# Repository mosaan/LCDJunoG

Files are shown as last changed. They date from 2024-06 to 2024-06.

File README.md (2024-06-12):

Roland Juno G LCD Emulator
==========================

LCD replacement project for Roland Juno G.
The original source is [dpeddi's work](https://github.com/dpeddi/LCDJunoG) under BSD-3-Clause license.
```
 * Copyright (c) 2022 Eddi De Pieri
 * Most code borrowed by Pico-DMX by Jostein Løwer 
 * Modified for performance by bjaan
```

Slight modifications as follows
- (WIP) LCD now uses 8-bit parallel mode for better refresh rate.
- Pin definitions in `platformio.ini` now work correctly. See `platformio.ini` for pinout notes.
- Fix few minor bugs.
- Refactor codes for better readability.
- Remove `MODE_BRIGHTNESS` and change functionality of `MODE_BGCOLOR`. (see below)

About `MODE_BGCOLOR`
====================

In `MODE_BGCOLOR`, you can control LCD background color with `LCD CONTRAST` knob on Juno G.

- In the first 3/4 of the knob, a color is selected from the hue ring according to the knob position.
- In the remaining 1/4 of the knob, the background color is fixed at white.

Without `MODE_BGCOLOR`, background color fixed to white.

PlatformIO Build Environments
=============================

There are 2 environments defined:
- `env:pico`: LCD runs in SPI mode.
- `env:pico-parallel`: LCD runs in 8bit parallel mode.

Althogh predefined pin assignments are carefully selected to make PCB creation easier,
you can choose other pins to match your needs.

BOM:
====

- Raspberry Pi Pico
- Display ILI9488 4.0” (purchased from [AliExpress](https://ja.aliexpress.com/item/1005003033844928.html))
- 1.0mm pitch 18-pin flexible flat cable. Length: 210mm (shorter might work), contacts on same side.
- FFC/FPC connector
  - 1.0mm pitch 18-pin, bottom connection; for Juno G connection.
  - (Needed in parallel mode only) 0.5mm pitch 40-pin, top connection; for LCD connection.
- 5 to 10 ohm reistor; for backlight LED on LCD.
- (Optional) 0.1uF ceramic capacitor; for "LCD CONTRAST" knob stability.

Predefined Pin Assignments (Parallel mode):
===========================================

| JunoG Pin | JunoG Function | RpiPico Pin |
| --- | --- | --- |
| 18 | +5V | VSYS |
| 17 | GND | GND |
| 16 | +3V | (Not used)  |
| 15 | RST | GP21 |
| 14 | CS2 (*1) | GP20 |
| 13 | CS1 (*1) | GP19 |
| 12 | RS | GP18 |
| 11 | WE | GP17 |
| 10 | D0 | GP8 |
| 9 | D1 | GP9 |
| 8 | D2 | GP10 |
| 7 | D3 | GP11 |
| 6 | D4 | GP12 |
| 5 | D5 | GP13 |
| 4 | D6 | GP14 |
| 3 | D7 | GP15 |
| 2 | BRGT | GP28 |
| 1 | BRGT Vref | +3V |

*1: Check if the pin configuration might be reversed

| LCD Pin# | LCD Function  | RpiPico Pin |
| --- | --- | --- |
| 40 | IM2 | GND |
| 39 | IM1 | 3.3V |
| 38 | IM0 | 3.3V |
| 37 | GND | GND |
| 36 | LED-K | GND |
| 35 | LED-K | GND |
| 34 | LED-K | GND |
| 33 | LED-A | (3.3V via resistor) |
| 32 | DB15 | (not used) |
| 31 | DB14 | (not used) |
| 30 | DB13 | (not used) |
| 29 | DB12 | (not used) |
| 28 | DB11 | (not used) |
| 27 | DB10 | (not used) |
| 26 | DB9 | (not used) |
| 25 | DB8 | (not used) |
| 24 | DB7 | GP7 |
| 23 | DB6 | GP6 |
| 22 | DB5 | GP5 |
| 21 | DB4 | GP4 |
| 20 | DB3 | GP3 |
| 19 | DB2 | GP2 |
| 18 | DB1 | GP1 |
| 17 | DB0 | GP0 |
| 16 | GND | GND |
| 15 | RESET | GP22 |
| 14 | SPI SDO | (not used) |
| 13 | SPI SDI/SDA | (not used) |
| 12 | RDX | 3.3V |
| 11 | WRX/SPI SCL | GP26 |
| 10 | DCX/RS(SPI-4) | GP27 |
| 9 | CSX/SPI CS | GND |
| 8 | FMARK(TE) | (not used) |
| 7 | VDDA | 3.3V |
| 6 | VDDI | 3.3V |
| 5 | GND | GND |
| 4 | YD | (not used) |
| 3 | XR | (not used) |
| 2 | YU | (not used) |
| 1 | XL | (not used) |

Predefined Pin Assignments (SPI mode):
======================================

| JunoG Pin | JunoG Function | RpiPico Pin |
| --- | --- | --- |
| 18 | +5V | VSYS |
| 17 | GND | GND |
| 16 | +3V | (Not used)  |
| 15 | RST | GP14 |
| 14 | CS1 | GP12 |
| 13 | CS2 | GP13 |
| 12 | RS | GP11 |
| 11 | WE | GP10 |
| 10 | D0 | GP2 |
| 9 | D1 | GP3 |
| 8 | D2 | GP4 |
| 7 | D3 | GP5 |
| 6 | D4 | GP6 |
| 5 | D5 | GP7 |
| 4 | D6 | GP8 |
| 3 | D7 | GP9 |
| 2 | BRGT | GP26 |
| 1 | BRGT Vref | +3V |

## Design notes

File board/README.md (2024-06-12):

# Reference board design

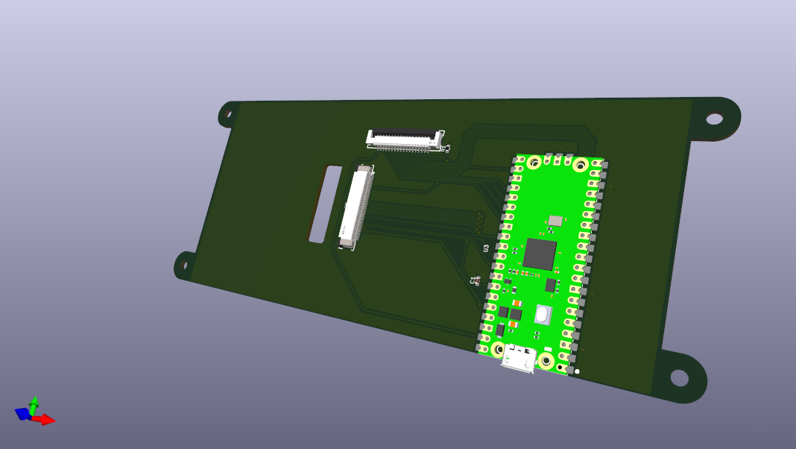
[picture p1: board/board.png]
reference board image


This directory contains [atopile](https://atopile.io/) & [KiCad](https://www.kicad.org/) project files for the reference board design.

If you just need PCB gerber files, see `elec/layout/default/production/board.zip`.

## Folder & File structure

- `ato.yaml`: atopile project setting file. see [atopile documentation](https://atopile.io/config/).
- `elec/`: main project files related with atopile and KiCad
  - `footprints/`: KiCad footprints & 3D shape datas.
  - `layout/`: KiCad project files.
  - `src/`: atopile module files.

## To modify & build your own gerber files

1. Modify `elec/src/board.ato` as you like.
2. [Install atopile](https://atopile.io/getting-started/) and run `ato install & ato build` in this folder, then you got netlist file at `build/default.net`.
3. Open `elec/layout/board.kicad_pro` in KiCad and open PCB file (or just open `elec/layout/board.kicad_pcb`).
4. From `File` menu, select `Import -> Netlist...`, then select the generated netlist file.
5. Now netlist updated as you write in `elec/src/board.ato`. Change board layout as you like!

Subsequent steps is the same as the usual board design in KiCad. Refer to  KiCad documentation.

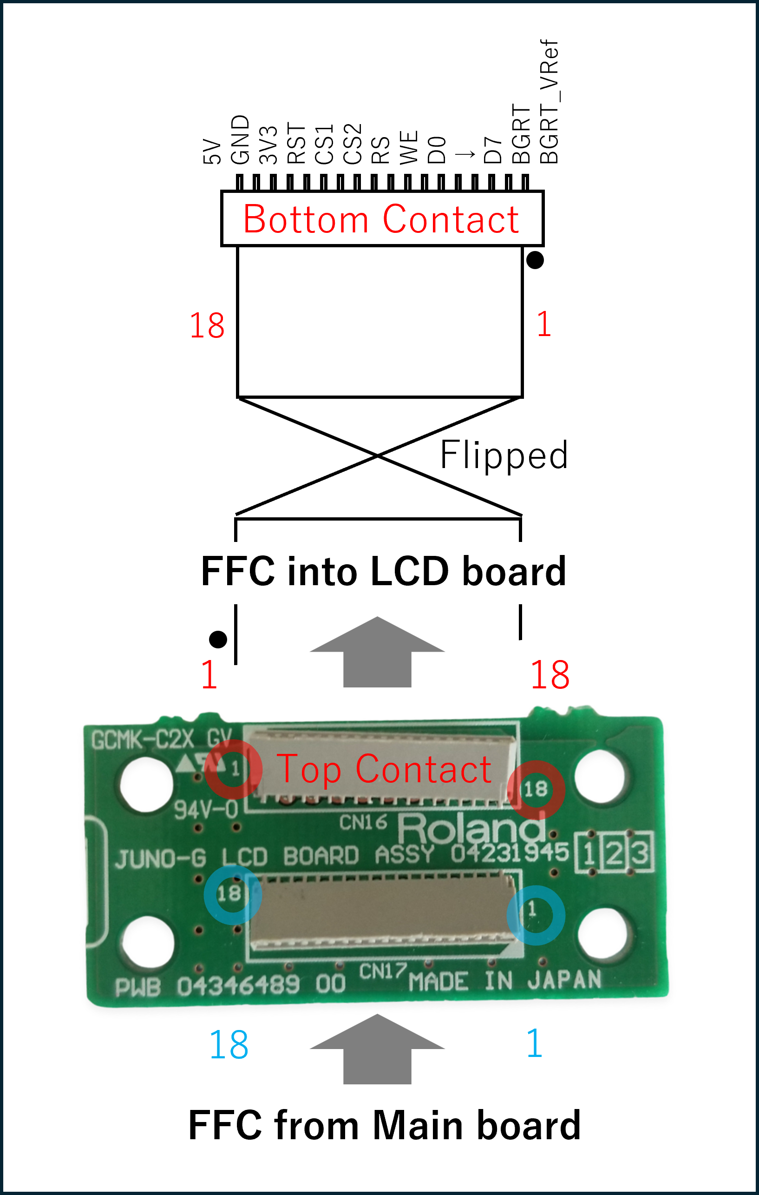
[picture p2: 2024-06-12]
docs/JunoG_to_LCDModule_connection_reference.png

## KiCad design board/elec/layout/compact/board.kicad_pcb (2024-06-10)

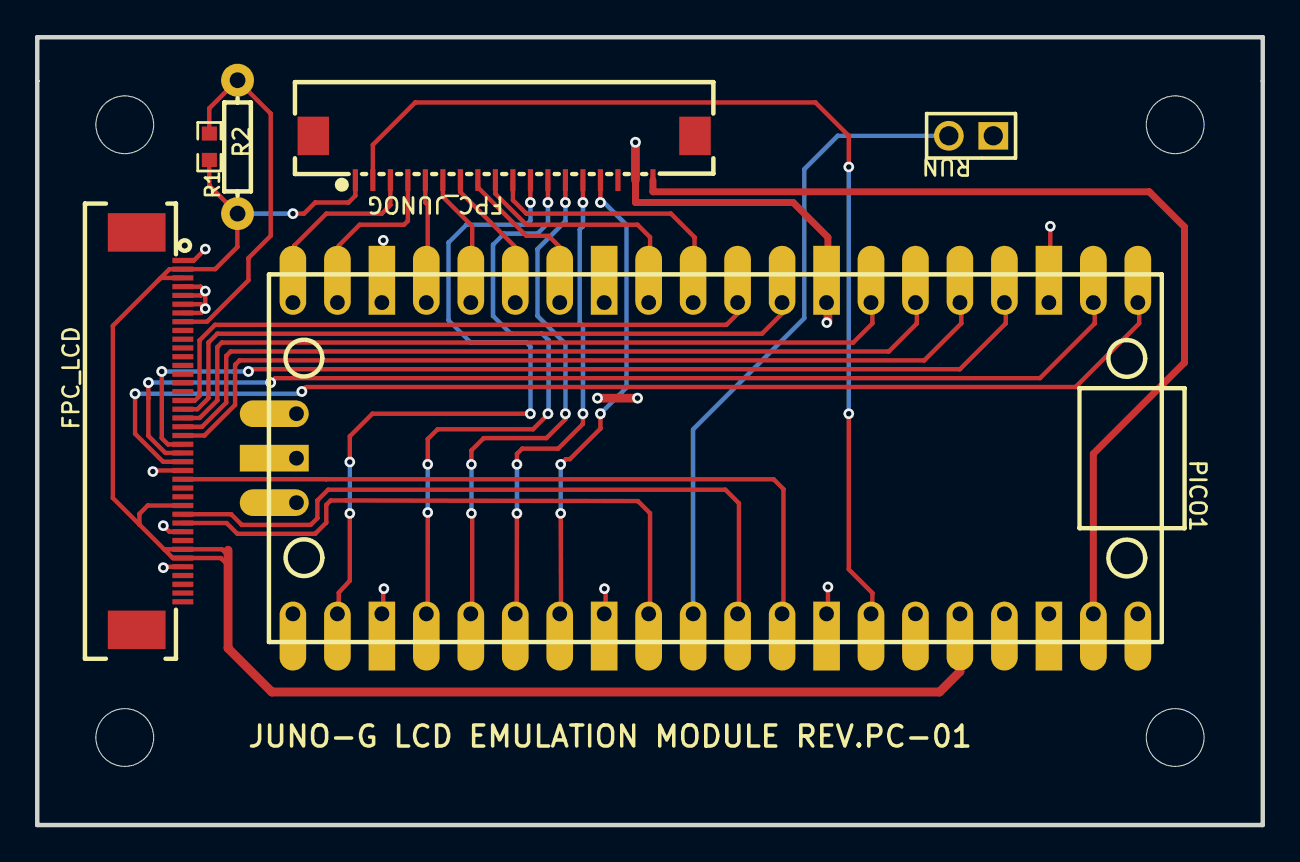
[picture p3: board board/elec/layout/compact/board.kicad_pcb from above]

Board: 2 copper layers, 70.0 x 45.0 mm, 10 parts (0 on the bottom side), 30 nets.

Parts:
FPC_JUNOG: 1.0K-DX-18PWB; FPC-SMD_18P-P1.00_HDGC_1.0K-DX-18PWB
FPC_LCD: AFC07-S40ECA-00; FPC-SMD_P0.50-40P_LCS-SJ-H2.0
Hole_gge3520: Hole_gge3520
Hole_gge3523: Hole_gge3523
Hole_gge3526: Hole_gge3526
Hole_gge3529: Hole_gge3529
PICO1: RASPBERRY-PI-PICO_TH/SMT (No Debug Pins); RASPBERRY-PI-PICO
R1: 5R1; R0603
R2: 5R1; R_AXIAL-0.3
RUN: HDR-M-2.54_1x2; HDR-M-2.54_1X2

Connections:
3.3V: FPC_JUNOG.1, FPC_LCD.2, FPC_LCD.3, FPC_LCD.29, FPC_LCD.34, FPC_LCD.35, PICO1.36, R1.1, R2.1
+5V: FPC_JUNOG.18, PICO1.39
BGRT: FPC_JUNOG.2, PICO1.34
CS1: FPC_JUNOG.14, PICO1.26
CS2: FPC_JUNOG.13, PICO1.25
D0: FPC_JUNOG.10, PICO1.11
D1: FPC_JUNOG.9, PICO1.12
D2: FPC_JUNOG.8, PICO1.14
D3: FPC_JUNOG.7, PICO1.15
D4: FPC_JUNOG.6, PICO1.16
D5: FPC_JUNOG.5, PICO1.17
D6: FPC_JUNOG.4, PICO1.19
D7: FPC_JUNOG.3, PICO1.20
FPC_LCD_8: FPC_LCD.8, R1.2, R2.2
GND: FPC_JUNOG.17, FPC_LCD.1, FPC_LCD.4, FPC_LCD.5, FPC_LCD.6, FPC_LCD.7, FPC_LCD.25, FPC_LCD.32, FPC_LCD.36, PICO1.3, PICO1.8, PICO1.13, PICO1.18, PICO1.23, PICO1.28, PICO1.33, PICO1.38, RUN.1
LCD_DB0: FPC_LCD.24, PICO1.1
LCD_DB1: FPC_LCD.23, PICO1.2
LCD_DB2: FPC_LCD.22, PICO1.4
LCD_DB3: FPC_LCD.21, PICO1.5
LCD_DB4: FPC_LCD.20, PICO1.6
LCD_DB5: FPC_LCD.19, PICO1.7
LCD_DB6: FPC_LCD.18, PICO1.9
LCD_DB7: FPC_LCD.17, PICO1.10
LCD_DC: FPC_LCD.31, PICO1.29
LCD_RST: FPC_LCD.26, PICO1.32
LCD_WR: FPC_LCD.30, PICO1.31
PICO1_30: PICO1.30, RUN.2
RS: FPC_JUNOG.12, PICO1.24
RST: FPC_JUNOG.15, PICO1.27
WE: FPC_JUNOG.11, PICO1.22

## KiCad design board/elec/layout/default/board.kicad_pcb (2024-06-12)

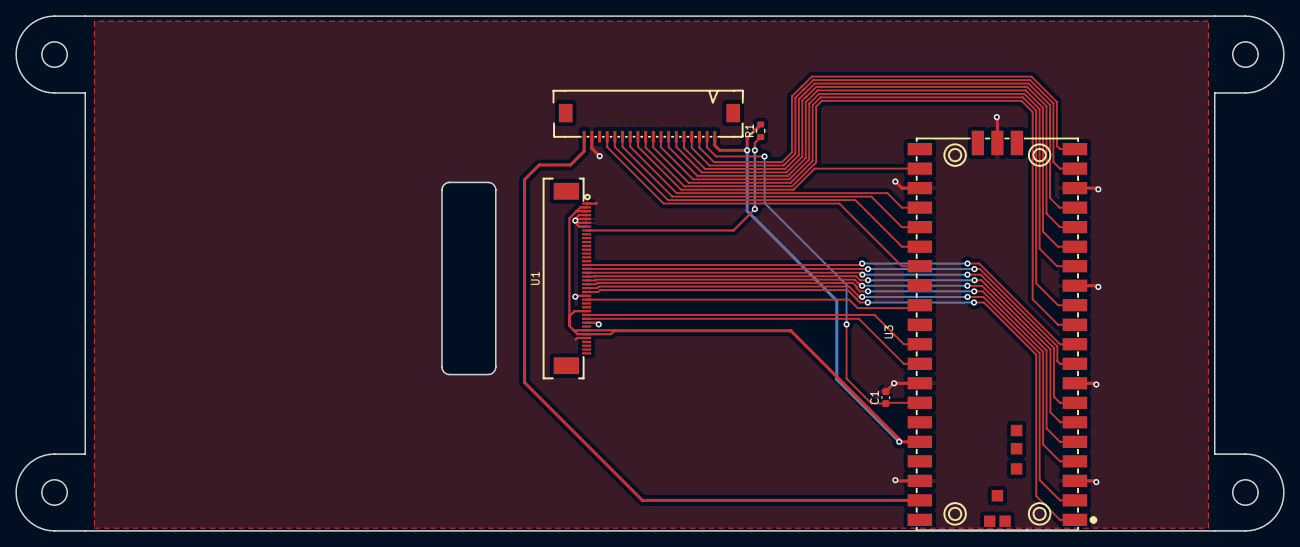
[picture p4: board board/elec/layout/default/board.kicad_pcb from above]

Board: 2 copper layers, 165.0 x 67.0 mm, 5 parts (0 on the bottom side), 29 nets.

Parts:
C1: 50V 100nF X7R ±10% 0603 Multilayer Ceramic Capaci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; C0603
R1: 100mW Thick Film Resistors 75V ±1% ±400ppm/℃ 10Ω 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; R0603
U1: FPC-SMD_P0.50-40P_LCS-SJ-H2.0
U2: FPC-SMD_AFA01-S18FCC-00
U3: COMM-SMD_L51.0-W21.0-P2.54_SC0916

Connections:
brgt: C1.1, U2.2, U3.34
cs1: U2.13, U3.25
cs2: U2.14, U3.26
d0: U2.10, U3.11
d1: U2.9, U3.12
d2: U2.8, U3.14
d3: U2.7, U3.15
d4: U2.6, U3.16
d5: U2.5, U3.17
d6: U2.4, U3.19
d7: U2.3, U3.20
db0: U1.24, U3.1
db1: U1.23, U3.2
db2: U1.22, U3.4
db3: U1.21, U3.5
db4: U1.20, U3.6
db5: U1.19, U3.7
db6: U1.18, U3.9
db7: U1.17, U3.10
dcx_rs_spi: U1.31, U3.32
gnd: C1.2, U1.1, U1.4, U1.5, U1.6, U1.7, U1.25, U1.32, U1.36, U2.17, U3.3, U3.8, U3.13, U3.18, U3.23, U3.28, U3.33, U3.38, U3.42
led_a: R1.1, U1.8
reset: U1.26, U3.29
rs: U2.12, U3.24
rst: U2.15, U3.27
vdd3: R1.2, U1.2, U1.3, U1.29, U1.34, U1.35, U2.1, U3.36
vdd5: U2.18, U3.39
we: U2.11, U3.22
wrx_spi_scl: U1.30, U3.31

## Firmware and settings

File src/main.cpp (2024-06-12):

/*
 * Copyright (c) 2022 Eddi De Pieri
 * Most code borrowed by Pico-DMX by Jostein Løwer 
 * Modified for performance by bjaan
 *
 * SPDX-License-Identifier: BSD-3-Clause
 * 
 * Description: 
 * Roland Juno G LCD Emulator
 */

// Define in setup to disable all #warnings in library (can be put in User_Setup_Select.h)
#define DISABLE_ALL_LIBRARY_WARNINGS
#ifdef DEBUG_SERIAL
#define DEBUG_PRINT(content) DEBUG_PRINT(content)
#else
#define DEBUG_PRINT(content) // do nothing.
#endif

#ifdef TFT_PARALLEL_8_BIT
// parallel mode does not need to call startWrite() and endWrite()
#define TFT_START_WRITE
#define TFT_END_WRITE
#else // SPI mode
#define TFT_START_WRITE tft.startWrite()
#define TFT_END_WRITE tft.endWrite()
#endif

#include <Arduino.h>

#include <SPI.h>
#include <TFT_eSPI.h> // Hardware-specific library
#ifdef DRAW_SPLASH
#include <LCDJunoG_splash.h>
#endif
#include <LCDJunoG_extra.h>

TFT_eSPI tft = TFT_eSPI();       // Invoke custom library

#include "LCDJunoG.h"
LCDJunoG lcdJunoG_cs1;
LCDJunoG lcdJunoG_cs2;

#include "constants.h"

uint tft_xoffset = 0;
uint tft_yoffset = 0;

/* 
  buffer_cs1[i]: raw data buffer sent from JUNO-G.

    bits:
    FEDCBA98 76543210 FEDCBA98 76543210
    ???????? ???????? ???????? vvvvvvvv
    s = R/S (INSTRUCTION/DATA REGISTER SELECTION) pin data (see JUNO_RS in platformio.ini and RS_PIN_RELATIVE_POSITION)
    v = value bits (8 bits: values 0 up to and including 255). y-axis values for 8 pixels packed into 1 byte.
*/
volatile uint32_t buffer_cs1[RAW_DATA_BUFFER_LENGTH];

/* 
  buffer_cs2[i]: raw data buffer sent from JUNO-G.

    bits:
    FEDCBA98 76543210 FEDCBA98 76543210
    ???????? ???????? ???????? vvvvvvvv
    s = R/S (INSTRUCTION/DATA REGISTER SELECTION) pin data (see JUNO_RS in platformio.ini and RS_PIN_RELATIVE_POSITION)
    v = value bits (8 bits: values 0 up to and including 255). y-axis values for 8 pixels packed into 1 byte.
*/
volatile uint32_t buffer_cs2[RAW_DATA_BUFFER_LENGTH];

// === buffer_cs1 and buffer_cs2 bit manipulation ===
// Extracts the value bits from the buffer_cs1 and buffer_cs2
#define VALUE_BITS(value) (value & 0xff)
// Extracts the RS bit from the buffer_cs1 and buffer_cs2
#define RS_BIT(value) ((value >> RS_PIN_RELATIVE_POSITION) & 1)

volatile uint8_t back_buffer[ORIGINAL_LCD_WIDTH][Y_PACKED_BYTES_LENGTH]; /* max X address register for CS1 and CS2 times max Y register */
volatile uint16_t pixel_x[ORIGINAL_LCD_WIDTH]; /* X location (pre-calculated) of actual pixel on new screen */
volatile uint16_t pixel_y[ORIGINAL_LCD_HEIGHT]; /* Y location (pre-calculated) of actual pixel on new screen */

#define ADC_RESOLUTION 6
uint32_t tft_fgcolor = TFT_BLACK;
uint32_t tft_bgcolor = TFT_WHITE;
uint32_t tft_bgcolor_prev = TFT_BLACK;

/*
  Draws a packed_pixels byte on the TFT screen at x,y_index

  arguments:
  - packed_pixels: 8 pixels packed into 1 byte. MSB is the top pixel, LSB is the bottom pixel.
  - y_index: the y index of the pixel. packed_pixels is drawn at y_index*8 up to and including y_index*8+7, thus 0 <= y_index < 12 (= Y_PACKED_BYTES_LENGTH).
  - x: the x address of the pixel
 */
void drawPixels(uint8_t packed_pixels, uint8_t x, uint8_t y_index) {
  int16_t real_x = pixel_x[x];
  int8_t y = y_index * 8;
  //for (int b = 0; b < 8; b++ ) {
  //  if (((packed_pixels >> b) & 0x1) == 1) tft.drawPixel(real_x, pixel_y[y+b], TFT_BLACK); else tft.drawPixel(real_x, pixel_y[y+b], TFT_WHITE);
  //}
  //unrolled loop for performance:
#if (TFT_PARALLEL_8_BIT & !FORCE_INTERLACE) // 8-bit parallel mode. fill pixels with fillRect()
  if ((packed_pixels & 0x1) == 0x1)   tft.fillRect(real_x, pixel_y[y++], ZOOM_X, ZOOM_Y, TFT_BLACK); else tft.fillRect(real_x, pixel_y[y++], ZOOM_X, ZOOM_Y, tft_bgcolor);
  if ((packed_pixels & 0x2) == 0x2)   tft.fillRect(real_x, pixel_y[y++], ZOOM_X, ZOOM_Y, TFT_BLACK); else tft.fillRect(real_x, pixel_y[y++], ZOOM_X, ZOOM_Y, tft_bgcolor);
  if ((packed_pixels & 0x4) == 0x4)   tft.fillRect(real_x, pixel_y[y++], ZOOM_X, ZOOM_Y, TFT_BLACK); else tft.fillRect(real_x, pixel_y[y++], ZOOM_X, ZOOM_Y, tft_bgcolor);
  if ((packed_pixels & 0x8) == 0x8)   tft.fillRect(real_x, pixel_y[y++], ZOOM_X, ZOOM_Y, TFT_BLACK); else tft.fillRect(real_x, pixel_y[y++], ZOOM_X, ZOOM_Y, tft_bgcolor);
  if ((packed_pixels & 0x10) == 0x10) tft.fillRect(real_x, pixel_y[y++], ZOOM_X, ZOOM_Y, TFT_BLACK); else tft.fillRect(real_x, pixel_y[y++], ZOOM_X, ZOOM_Y, tft_bgcolor);
  if ((packed_pixels & 0x20) == 0x20) tft.fillRect(real_x, pixel_y[y++], ZOOM_X, ZOOM_Y, TFT_BLACK); else tft.fillRect(real_x, pixel_y[y++], ZOOM_X, ZOOM_Y, tft_bgcolor);
  if ((packed_pixels & 0x40) == 0x40) tft.fillRect(real_x, pixel_y[y++], ZOOM_X, ZOOM_Y, TFT_BLACK); else tft.fillRect(real_x, pixel_y[y++], ZOOM_X, ZOOM_Y, tft_bgcolor);
  if ((packed_pixels & 0x80) == 0x80) tft.fillRect(real_x, pixel_y[y  ], ZOOM_X, ZOOM_Y, TFT_BLACK); else tft.fillRect(real_x, pixel_y[y  ], ZOOM_X, ZOOM_Y, tft_bgcolor);
#else // SPI mode. SPI is too slow to draw all LCD pixels. So we draw interlaced pixels.
  if ((packed_pixels & 0x1) == 0x1)   tft.drawPixel(real_x, pixel_y[y++], TFT_BLACK); else tft.drawPixel(real_x, pixel_y[y++], tft_bgcolor);
  if ((packed_pixels & 0x2) == 0x2)   tft.drawPixel(real_x, pixel_y[y++], TFT_BLACK); else tft.drawPixel(real_x, pixel_y[y++], tft_bgcolor);
  if ((packed_pixels & 0x4) == 0x4)   tft.drawPixel(real_x, pixel_y[y++], TFT_BLACK); else tft.drawPixel(real_x, pixel_y[y++], tft_bgcolor);
  if ((packed_pixels & 0x8) == 0x8)   tft.drawPixel(real_x, pixel_y[y++], TFT_BLACK); else tft.drawPixel(real_x, pixel_y[y++], tft_bgcolor);
  if ((packed_pixels & 0x10) == 0x10) tft.drawPixel(real_x, pixel_y[y++], TFT_BLACK); else tft.drawPixel(real_x, pixel_y[y++], tft_bgcolor);
  if ((packed_pixels & 0x20) == 0x20) tft.drawPixel(real_x, pixel_y[y++], TFT_BLACK); else tft.drawPixel(real_x, pixel_y[y++], tft_bgcolor);
  if ((packed_pixels & 0x40) == 0x40) tft.drawPixel(real_x, pixel_y[y++], TFT_BLACK); else tft.drawPixel(real_x, pixel_y[y++], tft_bgcolor);
  if ((packed_pixels & 0x80) == 0x80) tft.drawPixel(real_x, pixel_y[y  ], TFT_BLACK); else tft.drawPixel(real_x, pixel_y[y  ], tft_bgcolor);
#endif
}

void fillScreenWithBackgroundColor(uint32_t bgcolor) {
  TFT_START_WRITE;
#if (TFT_PARALLEL_8_BIT & !FORCE_INTERLACE) // 8-bit parallel mode. just fill screen with fillScreen().
  tft.fillScreen(bgcolor);
#else // SPI mode. SPI is too slow to draw all LCD pixels. So we draw interlaced pixels with bgcolor and all the rest filled with Black.
  tft.fillScreen(TFT_BLACK);
  for (uint x = 0; x < ORIGINAL_LCD_WIDTH; x++) {
    for (uint y = 0; y < Y_PACKED_BYTES_LENGTH; y++) {
        drawPixels(0, x, y);
    }
  }
#endif
  TFT_END_WRITE;
}

// convert hue to rgb565 value
// saturation and value are fixed to max value.
uint16_t inline rgb565FromHue(uint8_t hue) {
  uint8_t r = 0, g = 0, b = 0;
  if (hue < 85) {
    r = hue * 3;
    g = 255 - hue * 3;
  } else if (hue < 170) {
    hue -= 85;
    g = hue * 3;
    b = 255 - hue * 3;
  } else {
    hue -= 170;
    b = hue * 3;
    r = 255 - hue * 3;
  }
  return tft.color565(r, g, b);
}

void tft_change_bgcolor(uint32_t analog_read) {
  // we use upper 1/4 value of the ADC resolution as a threshold to switch between black and white mode.
  uint8_t mode_val = (analog_read >> (ADC_RESOLUTION - 2));
  // 2 MSBits are ignored
  uint8_t color_val = (analog_read & ((1 << (ADC_RESOLUTION - 2)) - 1));
  if(mode_val == 0b11) { // white mode
    tft_bgcolor = TFT_WHITE;
  } else {
    uint8_t hue = map(color_val, 0, (1 << (ADC_RESOLUTION - 2)) - 1, 0, 255);
    tft_bgcolor = rgb565FromHue(hue);
  }

  if (tft_bgcolor != tft_bgcolor_prev) {
    DEBUG_PRINT("force redraw");
    tft_bgcolor_prev = tft_bgcolor;
    fillScreenWithBackgroundColor(tft_bgcolor);
    for(uint8_t x = 0; x < ORIGINAL_LCD_WIDTH; x++) {
      for(uint8_t y = 0; y < Y_PACKED_BYTES_LENGTH; y++) {
        drawPixels(back_buffer[x][y], x, y);
      }
    }
  }
}

void setup()
{
  analogReadResolution(ADC_RESOLUTION);
  uint32_t analog_read = analogRead(JUNO_BRGT);
#ifdef DEBUG_SERIAL
  Serial.begin(115200);
  delay(2000);
  Serial.setTimeout(50);
#endif

  DEBUG_PRINT("juno g lcd emulator");
  tft.init();
  tft.setRotation(1);
#ifdef TFT_PARALLEL_8_BIT
  tft.initDMA(); // Enable DMA transfer for parallel mode
#endif
  tft_xoffset = (tft.width() - ORIGINAL_LCD_WIDTH * ZOOM_X) / 2 - ((tft.width() - ORIGINAL_LCD_WIDTH * ZOOM_X) / 2 % ZOOM_X);
  tft_yoffset = (tft.height() - ORIGINAL_LCD_HEIGHT * ZOOM_Y) / 2 - ((tft.height() - ORIGINAL_LCD_HEIGHT * ZOOM_Y) / 2 % ZOOM_Y);

#ifdef DRAW_SPLASH
  tft_change_bgcolor();
  drawBitmapZoom(0, 0, (const uint8_t *)junog, 240, 90, TFT_BLACK);
  delay(500);
#endif

  {  //precalculate new display pixel indices
    for (uint8_t x = 0; x < ORIGINAL_LCD_WIDTH; x++) {
      pixel_x[x] = tft_xoffset + x * ZOOM_X;
    }
    for (uint8_t y = 0; y < ORIGINAL_LCD_HEIGHT; y++) {
      pixel_y[y] = tft_yoffset + y * ZOOM_Y;
    }
  }
  { //initialize back buffer
    for (uint8_t x = 0; x < ORIGINAL_LCD_WIDTH; x++) {
      for (uint8_t y = 0; y < Y_PACKED_BYTES_LENGTH; y++) {
        back_buffer[x][y] = 0;
      }
    }
  }

#define DRAW_INFO
#ifdef DRAW_INFO
#ifdef MODE_BGCOLOR
  tft_change_bgcolor(analog_read);
#endif
  tft.setTextColor(TFT_BLACK);
  tft.setCursor(0, tft.height()/2 -10  , 2);
  tft.setTextSize(2);
  
  tft.setTextDatum(TC_DATUM);
  tft.drawString("JunoG LCD replacement V2.1.3", tft.width() /2, tft.height() / 2 - 20 );
  //tft.drawString("CPU_FREQ:" + String(rp2040.f_cpu()), tft.width() /2, tft.height() / 2 + 10 );
  delay(500);
  fillScreenWithBackgroundColor(tft_bgcolor);
#endif

#ifdef DRAW_PINOUT  
  drawPinout(1000);
#endif
   
  tft.setCursor(0, 0, 2);
  tft.setTextSize(1);
  
  // Setup our DMX Input to read on GPIO 0, from channel 1 to 3
  // TFT_eSPI uses all of instruction memory of pio0 or pio1,
  // so we use pio1 for both(CS1/CS2) chip monitoring to keep enough memory for TFT_eSPI.
  // (TFT_eSPI consumes 32 PIO instructions. see ".pio/libdeps/pico/TFT_eSPI/Processors/pio_SPI.pio.h")
  lcdJunoG_cs1.begin(JUNO_D0, /* pio0 */ pio1, 1);
  lcdJunoG_cs2.begin(JUNO_D0, pio1, 2);
  lcdJunoG_cs1.read_async(buffer_cs1);
  lcdJunoG_cs2.read_async(buffer_cs2);

  // Setup the onboard LED so that we can blink when we receives packets
  pinMode(LED_BUILTIN, OUTPUT);
  DEBUG_PRINT("Setup finished");
}

volatile uint8_t x_cs1 = 0; //X address counter for CS1: 7 bit: values 0 up and to including 127: actually max. 120
volatile uint8_t x_cs2 = CS2_X_OFFSET; //X address counter for CS2: 7 bit: values 0 up and to including 127: actually max. 120. Here it is set, and later reset to 120, to avoid having to add an offset of 120 all the time
volatile uint8_t y_cs1 = 0; //Y address register for CS1: 4 bit: values 0 up and to including 15: actually max. 12 as 12*8 = 96
volatile uint8_t y_cs2 = 0; //Y address register for CS2: 4 bit: values 0 up and to including 15: actually max. 12 as 12*8 = 96

bool led_on = false;
unsigned long latest_packet_timestamp_cs1 = 0;
unsigned long latest_packet_timestamp_cs2 = 0;

int period = 500;
unsigned long time_last_adc_read = 0;
unsigned long time_now = 0;

void loop()
{
// TODO: Move the other core to handle bgcolor changes
#if MODE_BGCOLOR | DEBUG_READ
  time_now = millis();

  if(time_now - time_last_adc_read >= period) {
    DEBUG_PRINT("ADC read");
    time_last_adc_read = time_now;
    int analog_read = analogRead(JUNO_BRGT);
#ifdef MODE_BGCOLOR
    tft_change_bgcolor(analog_read);
#endif
#ifdef DEBUG_READ
    tft.fillRect(tft.width() / 2 - 40, 0, 80, 14, TFT_BLACK);
    tft.setTextColor(tft_bgcolor);
    tft.setCursor(tft.width() /2 - 40 , 0, 2);
    tft.setTextSize(1);
  
    tft.setTextDatum(TC_DATUM);
    tft.drawString(String(analog_read) + String("/") + String(time_last_adc_read), tft.width() /2, 0);
#endif
    DEBUG_PRINT("ADC read done");
  }
#endif // MODE_BGCOLOR | DEBUG_READ

  if(latest_packet_timestamp_cs1 == lcdJunoG_cs1.latest_packet_timestamp() && latest_packet_timestamp_cs2 == lcdJunoG_cs2.latest_packet_timestamp()) {
    return; // no packet received
  }
  DEBUG_PRINT("packet received");
  latest_packet_timestamp_cs1 = lcdJunoG_cs1.latest_packet_timestamp();
  latest_packet_timestamp_cs2 = lcdJunoG_cs2.latest_packet_timestamp();
  TFT_START_WRITE;
  DEBUG_PRINT("start write");
  for (uint i = 0; i < RAW_DATA_BUFFER_LENGTH; i++)  
  {
    { //CS 1
      uint8_t val = VALUE_BITS(buffer_cs1[i]);
      uint8_t rs = RS_BIT(buffer_cs1[i]);
      if (rs == 0) { //INSTRUCTION REGISTER
#ifdef SHOWCMD
          showcmd( cs, val );
#endif
      // JUNO-G has KS0713 like LCD controller. It has 2 display data RAMs. One for the left hand part and one for the right hand part.
      if ((val & 0xf0 /*11110000*/) == 0xb0 /*10110000*/) { //Sets the Y address at the Y address register
          y_cs1 = val & 0x0f /*00001111*/;
          x_cs1 = 0;
        }
      } else if (rs == 1) { //DATA REGISTER
        //writes data on JUNO_D0 to JUNO_D7 pins into display data RAM.
        if (x_cs1 < CS2_X_OFFSET) {  // avoid overflow
          if (back_buffer[x_cs1][y_cs1] != val) { // only draw if value has changed for performance
            back_buffer[x_cs1][y_cs1] = val;
            drawPixels(val, x_cs1, y_cs1);
          }
          x_cs1++; //After the writing instruction, X address is increased by 1 automatically.
        }
      }    
    }
    { //CS 2
      uint8_t val = VALUE_BITS(buffer_cs2[i]);
      uint8_t rs = RS_BIT(buffer_cs2[i]);
      if (rs == 0) { //INSTRUCTION REGISTER
#ifdef SHOWCMD
        showcmd( cs, val );
#endif
        if ((val & 0xf0 /*11110000*/) == 0xb0 /*1011000*/) { //Sets the X address at the X address register
          y_cs2 = val & 0x0f /*00001111*/;
          x_cs2 = CS2_X_OFFSET; // 120 is left most pixel of the right hand part
        }
      } else if (rs == 1) { //DATA REGISTER
        //writes data on JUNO_D0 to JUNO_D7 pins into display data RAM.
        if (x_cs2 >= CS2_X_OFFSET && x_cs2 < ORIGINAL_LCD_WIDTH) {  // avoid overflow  
          if (back_buffer[x_cs2][y_cs2] != val) {
            back_buffer[x_cs2][y_cs2] = val;
            drawPixels(val, x_cs2, y_cs2);
          }
          x_cs2++; //After the writing instruction, Y address is increased by 1 automatically.
        }
      }
    }
  }
  DEBUG_PRINT("cs1/2 processed");
  TFT_END_WRITE;
  DEBUG_PRINT("end write");
  // Blink the LED to indicate that a packet was received
  if (!led_on) digitalWrite(LED_BUILTIN, HIGH); else digitalWrite(LED_BUILTIN, LOW);
  led_on = !led_on;
  DEBUG_PRINT("packet processed");
}

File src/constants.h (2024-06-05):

#define ZOOM_X 2
#define ZOOM_Y 3
#define ORIGINAL_LCD_WIDTH 240
#define ORIGINAL_LCD_HEIGHT 96
#define Y_PACKED_BYTES_LENGTH (ORIGINAL_LCD_HEIGHT / 8) // Original LCD has 96 pixels in Y direction, but 8 pixels are packed into 1 byte.
#define ORIGINAL_LCD_PART_X_MAX_ADDRESS 123 // max X address for CS1 and CS2. Last 3 pixels are not used.
#define RAW_DATA_BUFFER_LENGTH (ORIGINAL_LCD_PART_X_MAX_ADDRESS * Y_PACKED_BYTES_LENGTH)
#define CS2_X_OFFSET 120 // X offset for CS2. CS2 starts at X address 120.

// R/S (INSTRUCTION/DATA REGISTER SELECTION) pin position in the buffer_cs1 and buffer_cs2.
// The position is relative to the D0 pin.
#define RS_PIN_RELATIVE_POSITION ((32 + JUNO_RS - JUNO_D0) % 32)

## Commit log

2024-06-02 replace magic numbers to macros and add some comments.
    [LCDJunoG.cpp, LCDJunoG.pio.h, main.cpp]
2024-06-03 bugfix when made renaming
    [main.cpp]
2024-06-03 replace buffer size from 16 to 32 and fetch all pins' state for flexible pin assignment.
    [LCDJunoG.cpp, LCDJunoG.pio.h, main.cpp]
2024-06-06 add parallel mode pcb garber and corresponding settings.
    [Drill_NPTH_Through.DRL, Drill_PTH_Through.DRL, Drill_PTH_Through_Via.DRL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]
2024-06-06 fix incorrect pin assign
2024-06-06 bugfix: fix incorrect modification of "LCDJunoG.cpp"
    [LCDJunoG.cpp]
2024-06-07 fix pin assign documentation.
2024-06-08 fix time counter type for adc.
    [main.cpp]
2024-06-10 add reference PCB file (v1)
    [Drill_NPTH_Through.DRL, Drill_PTH_Through.DRL, Drill_PTH_Through_Via.DRL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]
2024-06-10 correct 3d model settings.
    [board.kicad_pcb]
2024-06-10 replace Pi Pico 3d model
2024-06-10 コンパクト万事知事保存
    [board.kicad_pcb, board.kicad_sch]
2024-06-11 replace value with constant.
    [LCDJunoG.cpp]
2024-06-12 add a resistor in BOM.
2024-06-12 fix 3d model path of Pi Pico
    [board.kicad_pcb]
2024-06-12 add board image.
